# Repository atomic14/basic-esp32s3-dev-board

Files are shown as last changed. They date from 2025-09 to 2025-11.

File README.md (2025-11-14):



# Very Basic ESP32-S3 Dev Board

More details available with this video [here](https://youtu.be/YMnd2NHENCI)

Design Video (https://www.youtube.com/watch?v=enlcWor7sPM)

Assembly Video (https://youtu.be/KziOUBjNtWw)

This is a super simple ESP32-S3 Dev Board with the bare mininum required to get it working.



We have:

- USB-C connector with 5.1K pull down resistors on CC1 and CC2
- 3V3 LDO Regulator
- Decoupling Capacitors
- indicated LEDs - 5V, 3V3, GPIO21

Things that we don't have:

- Additonal ESD protection on the USB port
- Battery charging and power path control
- Any exciting peripherals

## Schematic

- View the schematic PDF: [docs/schematic.pdf](docs/schematic.pdf)

Schematic

## PCB

PCB Render

- 3D Model (STEP): [docs/dev-board.step](docs/dev-board.step)

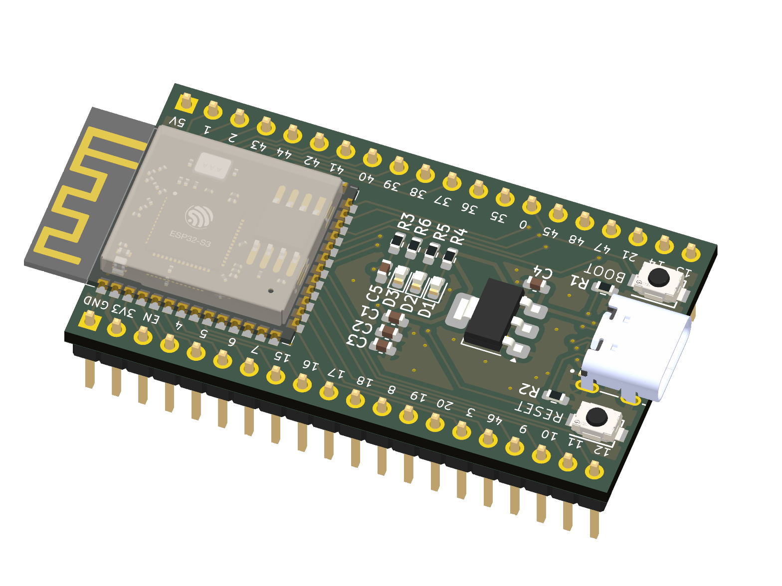
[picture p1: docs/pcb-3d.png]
3D Model


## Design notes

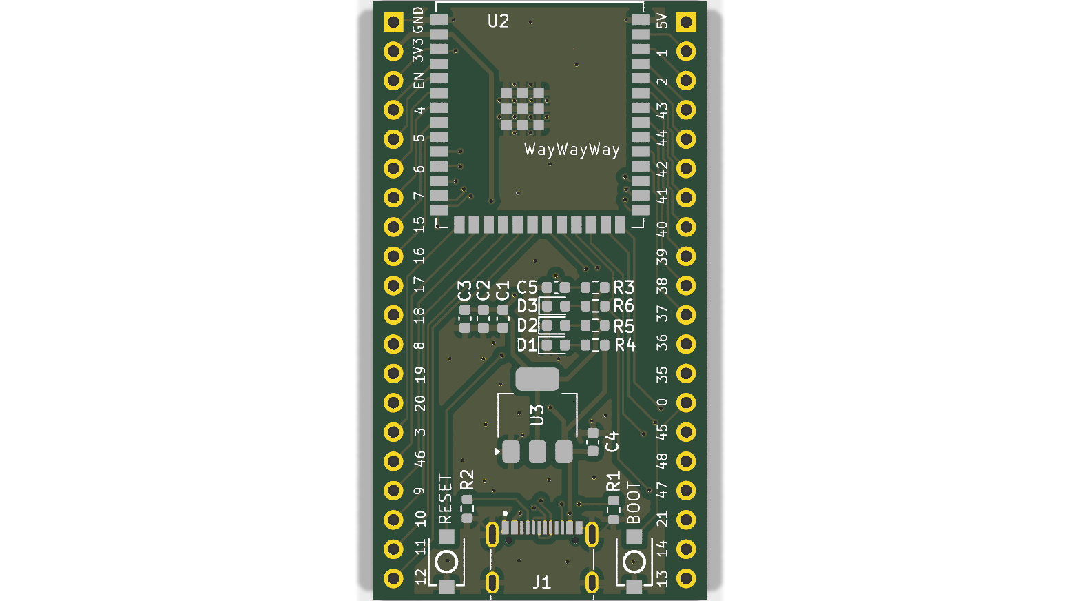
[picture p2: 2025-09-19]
docs/pcb.png

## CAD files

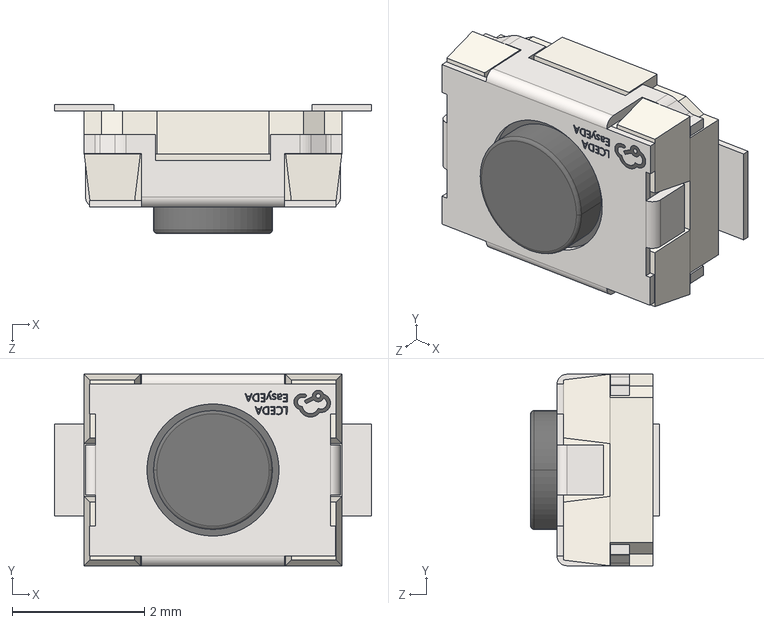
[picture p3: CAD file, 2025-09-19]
3d-models/SW-SMD_L3.9-W2.9-H2.0-LS4.8.step
4.80 x 2.90 x 1.95 mm

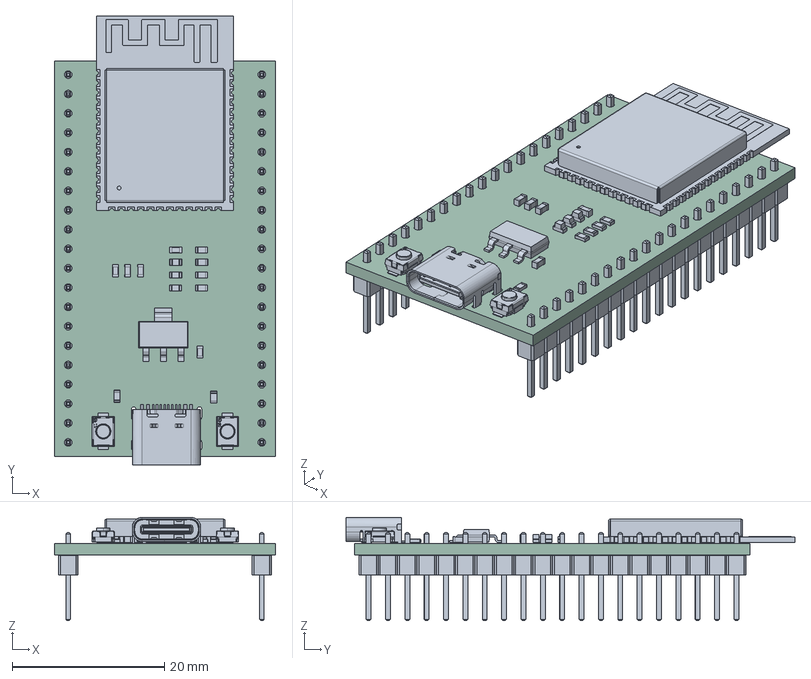
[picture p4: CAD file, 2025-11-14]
docs/dev-board.step
29.0 x 58.9 x 13.5 mm
R_0603_1608Metric x 6
SW-SMD_L3.9-W2.9-H2.0-LS4.8 x 2
LED_0603_1608Metric x 3
C_0603_1608Metric x 5
TYPE-C-31-M-12
SOT-223
C0201_20210301.STEP^C0201_20210301.STEP_Submodel-C0201_part_ DesignRootModel_PCB_ESP32-S3-WROOM-1_V1(2)_PCB_ESP32-S3-WROOM-1_V1 x 14
L0201_20210301.STEP^L0201_20210301.STEP_Submodel-L0201_part_ DesignRootModel_PCB_ESP32-S3-WROOM-1_V1(2)_PCB_ESP32-S3-WROOM-1_V1 x 3
C0402_20210301.STEP^C0402_20210301.STEP_Submodel-C0402_part_ DesignRootModel_PCB_ESP32-S3-WROOM-1_V1(2)_PCB_ESP32-S3-WROOM-1_V1
R0201_20210301.STEP^R0201_20210301.STEP_Submodel-R0201_part_ DesignRootModel_PCB_ESP32-S3-WROOM-1_V1(2)_PCB_ESP32-S3-WROOM-1_V1 x 8
trace_1^Submodel-MINI-ANT-TYPEB_668419613_part_DesignRootModel_PCB_ ESP32-S3-WROOM-1_V1(2)_PCB_ESP32-S3-WROOM-1_V1
DFN1006.STEP^DFN1006.STEP_Submodel-SOD882_part_DesignRootModel_PCB_ ESP32-S3-WROOM-1_V1(2)_PCB_ESP32-S3-WROOM-1_V1
SOP8_rev1_20210308.STEP^SOP8_rev1_20210308.STEP_Submodel-SOP8_1P27_6P6_ part_DesignRootModel_PCB_ESP32-S3-WROOM-1_V1(2)_PCB_ESP32-S3-WROOM-1_V1
XTAL3225_20210301.STEP^XTAL3225_20210301.STEP_Submodel-XTAL3225_part_ DesignRootModel_PCB_ESP32-S3-WROOM-1_V1(2)_PCB_ESP32-S3-WROOM-1_V1
ESP32-S3_20210301.STEP^ESP32-S3_20210301.STEP_Submodel-QFN56_0P4_7_ part_DesignRootModel_PCB_ESP32-S3-WROOM-1_V1(2)_PCB_ESP32-S3-WROOM-1_V1
uid__4-128^DesignRootModel_PCB_ESP32-S3-WROOM-1_V1(2)_PCB_ ESP32-S3-WROOM-1_V1
uid__4-129^DesignRootModel_PCB_ESP32-S3-WROOM-1_V1(2)_PCB_ ESP32-S3-WROOM-1_V1
uid__4-130^DesignRootModel_PCB_ESP32-S3-WROOM-1_V1(2)_PCB_ ESP32-S3-WROOM-1_V1
uid__4-149^DesignRootModel_PCB_ESP32-S3-WROOM-1_V1(2)_PCB_ ESP32-S3-WROOM-1_V1
uid__4-150^DesignRootModel_PCB_ESP32-S3-WROOM-1_V1(2)_PCB_ ESP32-S3-WROOM-1_V1
uid__4-151^DesignRootModel_PCB_ESP32-S3-WROOM-1_V1(2)_PCB_ ESP32-S3-WROOM-1_V1
uid__4-167^DesignRootModel_PCB_ESP32-S3-WROOM-1_V1(2)_PCB_ ESP32-S3-WROOM-1_V1
uid__4-168^DesignRootModel_PCB_ESP32-S3-WROOM-1_V1(2)_PCB_ ESP32-S3-WROOM-1_V1
uid__4-169^DesignRootModel_PCB_ESP32-S3-WROOM-1_V1(2)_PCB_ ESP32-S3-WROOM-1_V1
uid__1-279^DesignRootModel_PCB_ESP32-S3-WROOM-1_V1(2)_PCB_ ESP32-S3-WROOM-1_V1
uid__1-280^DesignRootModel_PCB_ESP32-S3-WROOM-1_V1(2)_PCB_ ESP32-S3-WROOM-1_V1
uid__1-292^DesignRootModel_PCB_ESP32-S3-WROOM-1_V1(2)_PCB_ ESP32-S3-WROOM-1_V1
uid__1-298^DesignRootModel_PCB_ESP32-S3-WROOM-1_V1(2)_PCB_ ESP32-S3-WROOM-1_V1
uid__1-299^DesignRootModel_PCB_ESP32-S3-WROOM-1_V1(2)_PCB_ ESP32-S3-WROOM-1_V1
uid__1-300^DesignRootModel_PCB_ESP32-S3-WROOM-1_V1(2)_PCB_ ESP32-S3-WROOM-1_V1
uid__1-301^DesignRootModel_PCB_ESP32-S3-WROOM-1_V1(2)_PCB_ ESP32-S3-WROOM-1_V1
uid__1-304^DesignRootModel_PCB_ESP32-S3-WROOM-1_V1(2)_PCB_ ESP32-S3-WROOM-1_V1
uid__1-305^DesignRootModel_PCB_ESP32-S3-WROOM-1_V1(2)_PCB_ ESP32-S3-WROOM-1_V1
uid__1-308^DesignRootModel_PCB_ESP32-S3-WROOM-1_V1(2)_PCB_ ESP32-S3-WROOM-1_V1
uid__1-310^DesignRootModel_PCB_ESP32-S3-WROOM-1_V1(2)_PCB_ ESP32-S3-WROOM-1_V1
uid__1-311^DesignRootModel_PCB_ESP32-S3-WROOM-1_V1(2)_PCB_ ESP32-S3-WROOM-1_V1
uid__1-325^DesignRootModel_PCB_ESP32-S3-WROOM-1_V1(2)_PCB_ ESP32-S3-WROOM-1_V1
uid__1-334^DesignRootModel_PCB_ESP32-S3-WROOM-1_V1(2)_PCB_ ESP32-S3-WROOM-1_V1
uid__1-338^DesignRootModel_PCB_ESP32-S3-WROOM-1_V1(2)_PCB_ ESP32-S3-WROOM-1_V1
uid__1-339^DesignRootModel_PCB_ESP32-S3-WROOM-1_V1(2)_PCB_ ESP32-S3-WROOM-1_V1
uid__1-340^DesignRootModel_PCB_ESP32-S3-WROOM-1_V1(2)_PCB_ ESP32-S3-WROOM-1_V1
uid__1-343^DesignRootModel_PCB_ESP32-S3-WROOM-1_V1(2)_PCB_ ESP32-S3-WROOM-1_V1
uid__1-344^DesignRootModel_PCB_ESP32-S3-WROOM-1_V1(2)_PCB_ ESP32-S3-WROOM-1_V1
uid__1-345^DesignRootModel_PCB_ESP32-S3-WROOM-1_V1(2)_PCB_ ESP32-S3-WROOM-1_V1
uid__1-352^DesignRootModel_PCB_ESP32-S3-WROOM-1_V1(2)_PCB_ ESP32-S3-WROOM-1_V1
uid__1-354^DesignRootModel_PCB_ESP32-S3-WROOM-1_V1(2)_PCB_ ESP32-S3-WROOM-1_V1
uid__1-355^DesignRootModel_PCB_ESP32-S3-WROOM-1_V1(2)_PCB_ ESP32-S3-WROOM-1_V1
uid__1-357^DesignRootModel_PCB_ESP32-S3-WROOM-1_V1(2)_PCB_ ESP32-S3-WROOM-1_V1
uid__1-358^DesignRootModel_PCB_ESP32-S3-WROOM-1_V1(2)_PCB_ ESP32-S3-WROOM-1_V1
uid__1-359^DesignRootModel_PCB_ESP32-S3-WROOM-1_V1(2)_PCB_ ESP32-S3-WROOM-1_V1
uid__1-364^DesignRootModel_PCB_ESP32-S3-WROOM-1_V1(2)_PCB_ ESP32-S3-WROOM-1_V1
uid__1-365^DesignRootModel_PCB_ESP32-S3-WROOM-1_V1(2)_PCB_ ESP32-S3-WROOM-1_V1
uid__1-371^DesignRootModel_PCB_ESP32-S3-WROOM-1_V1(2)_PCB_ ESP32-S3-WROOM-1_V1
uid__1-375^DesignRootModel_PCB_ESP32-S3-WROOM-1_V1(2)_PCB_ ESP32-S3-WROOM-1_V1
uid__1-376^DesignRootModel_PCB_ESP32-S3-WROOM-1_V1(2)_PCB_ ESP32-S3-WROOM-1_V1
uid__1-378^DesignRootModel_PCB_ESP32-S3-WROOM-1_V1(2)_PCB_ ESP32-S3-WROOM-1_V1
uid__1-379^DesignRootModel_PCB_ESP32-S3-WROOM-1_V1(2)_PCB_ ESP32-S3-WROOM-1_V1
uid__1-380^DesignRootModel_PCB_ESP32-S3-WROOM-1_V1(2)_PCB_ ESP32-S3-WROOM-1_V1
uid__1-381^DesignRootModel_PCB_ESP32-S3-WROOM-1_V1(2)_PCB_ ESP32-S3-WROOM-1_V1
uid__1-382^DesignRootModel_PCB_ESP32-S3-WROOM-1_V1(2)_PCB_ ESP32-S3-WROOM-1_V1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

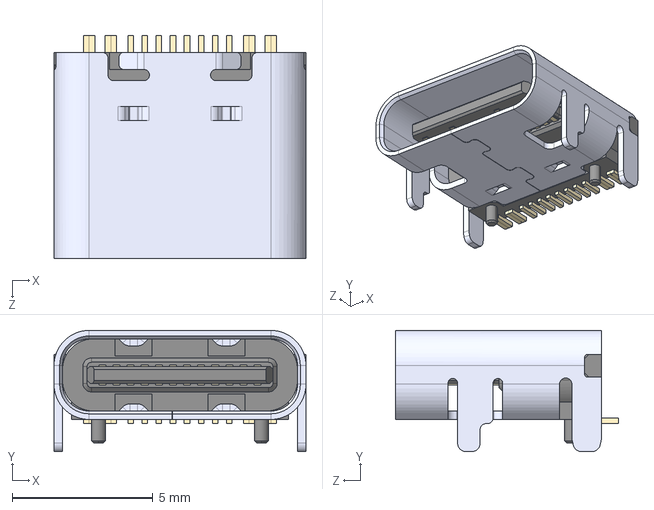
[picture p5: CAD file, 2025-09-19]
3d-models/TYPE-C-31-M-12.step
8.94 x 4.30 x 7.90 mm

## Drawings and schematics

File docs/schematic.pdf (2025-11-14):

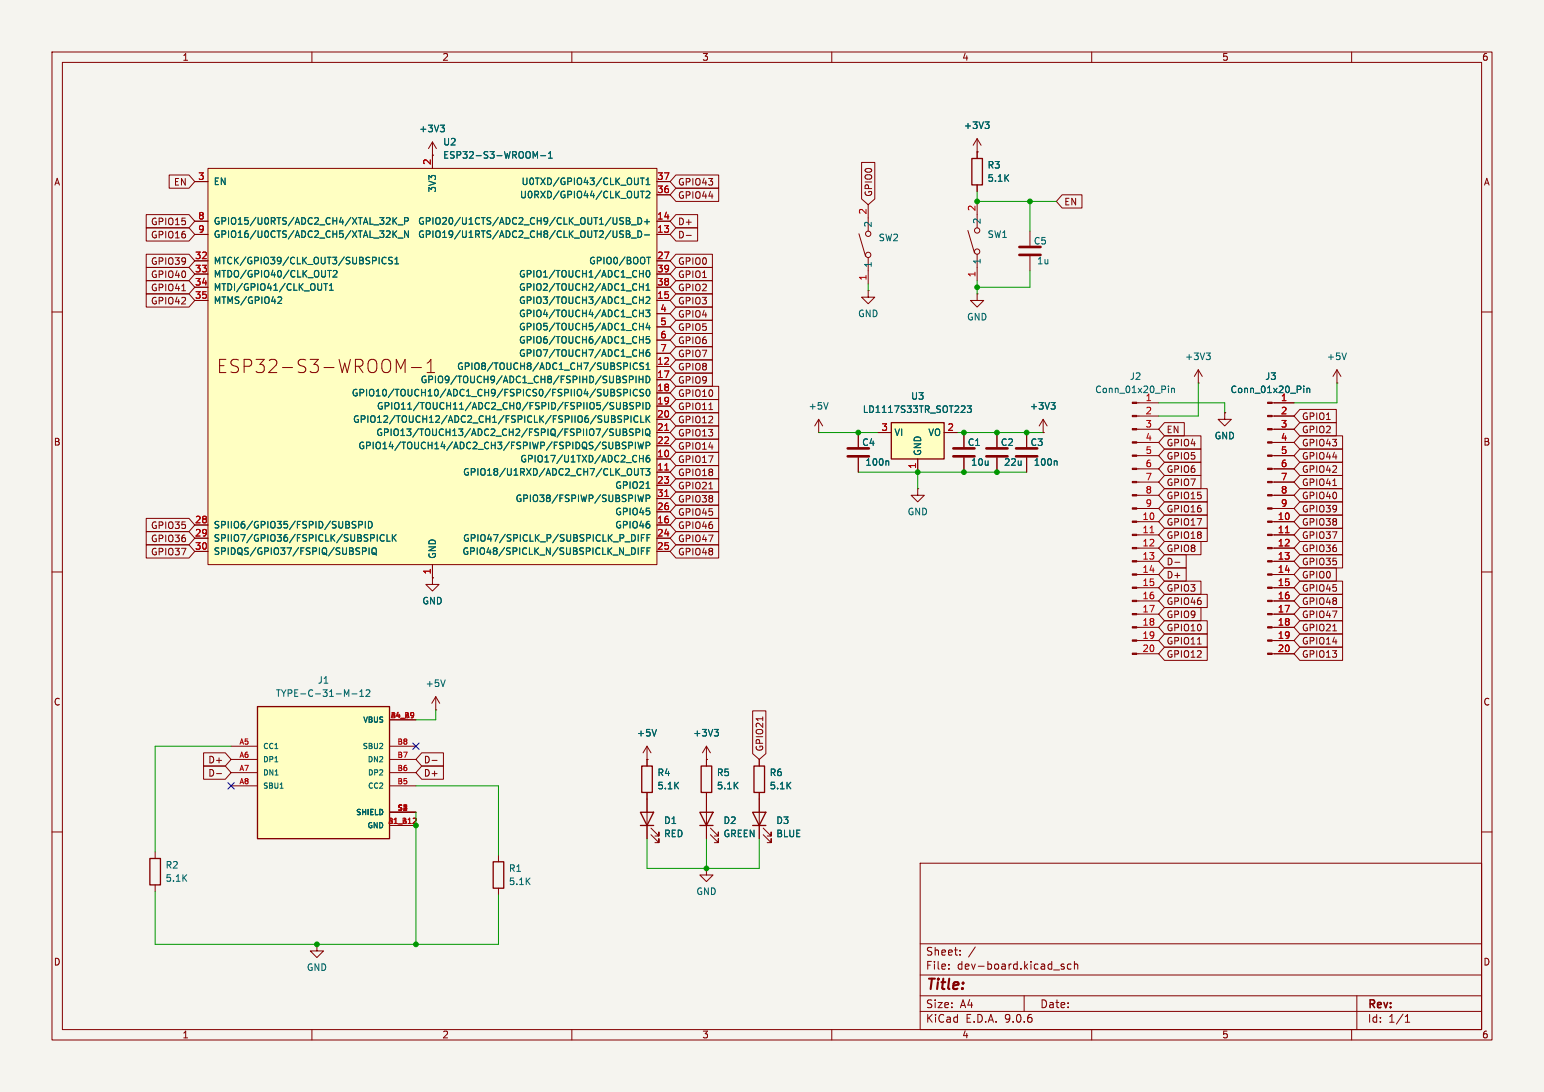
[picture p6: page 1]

1 U0TXD/GPIO43/CLK_OUT1 37 U0RXD/GPIO44/CLK_OUT2 36 GPIO20/U1CTS/ADC2_CH9/CLK_OUT1/USB_D+ 14 GPIO19/U1RTS/ADC2_CH8/CLK_OUT2/USB_D- 13 GPIO0/BOOT 27 GPIO1/TOUCH1/ADC1_CH0 39 GPIO2/TOUCH2/ADC1_CH1 38 GPIO3/TOUCH3/ADC1_CH2 15 GPIO4/TOUCH4/ADC1_CH3 4 GPIO5/TOUCH5/ADC1_CH4 5 GPIO6/TOUCH6/ADC1_CH5 6 GPIO7/TOUCH7/ADC1_CH6 7 GPIO8/TOUCH8/ADC1_CH7/SUBSPICS1 12 GPIO9/TOUCH9/ADC1_CH8/FSPIHD/SUBSPIHD 17 GPIO10/TOUCH10/ADC1_CH9/FSPICS0/FSPIIO4/SUBSPICS0 18 GPIO11/TOUCH11/ADC2_CH0/FSPID/FSPIIO5/SUBSPID 19 GPIO12/TOUCH12/ADC2_CH1/FSPICLK/FSPIIO6/SUBSPICLK 20 GPIO13/TOUCH13/ADC2_CH2/FSPIQ/FSPIIO7/SUBSPIQ 21 GPIO14/TOUCH14/ADC2_CH3/FSPIWP/FSPIDQS/SUBSPIWP 22 GPIO17/U1TXD/ADC2_CH6 10 GPIO18/U1RXD/ADC2_CH7/CLK_OUT3 11 GPIO21 23 GPIO38/FSPIWP/SUBSPIWP 31 GPIO45 26 GPIO46 16 GPIO47/SPICLK_P/SUBSPICLK_P_DIFF 24 GPIO48/SPICLK_N/SUBSPICLK_N_DIFF 25 U2ESP32-S3-WROOM-1 R6

1 U0TXD/GPIO43/CLK_OUT1 37 U0RXD/GPIO44/CLK_OUT2 36 GPIO20/U1CTS/ADC2_CH9/CLK_OUT1/USB_D+ 14 GPIO19/U1RTS/ADC2_CH8/CLK_OUT2/USB_D- 13 GPIO0/BOOT 27 GPIO1/TOUCH1/ADC1_CH0 39 GPIO2/TOUCH2/ADC1_CH1 38 GPIO3/TOUCH3/ADC1_CH2 15 GPIO4/TOUCH4/ADC1_CH3 4 GPIO5/TOUCH5/ADC1_CH4 5 GPIO6/TOUCH6/ADC1_CH5 6 GPIO7/TOUCH7/ADC1_CH6 7 GPIO8/TOUCH8/ADC1_CH7/SUBSPICS1 12 GPIO9/TOUCH9/ADC1_CH8/FSPIHD/SUBSPIHD 17 GPIO10/TOUCH10/ADC1_CH9/FSPICS0/FSPIIO4/SUBSPICS0 18 GPIO11/TOUCH11/ADC2_CH0/FSPID/FSPIIO5/SUBSPID 19 GPIO12/TOUCH12/ADC2_CH1/FSPICLK/FSPIIO6/SUBSPICLK 20 GPIO13/TOUCH13/ADC2_CH2/FSPIQ/FSPIIO7/SUBSPIQ 21 GPIO14/TOUCH14/ADC2_CH3/FSPIWP/FSPIDQS/SUBSPIWP 22 GPIO17/U1TXD/ADC2_CH6 10 GPIO18/U1RXD/ADC2_CH7/CLK_OUT3 11 GPIO21 23 GPIO38/FSPIWP/SUBSPIWP 31 GPIO45 26 GPIO46 16 GPIO47/SPICLK_P/SUBSPICLK_P_DIFF 24 GPIO48/SPICLK_N/SUBSPICLK_N_DIFF 25 C3

Id: 1/1 Title: File: dev-board.kicad_sch Sheet: /

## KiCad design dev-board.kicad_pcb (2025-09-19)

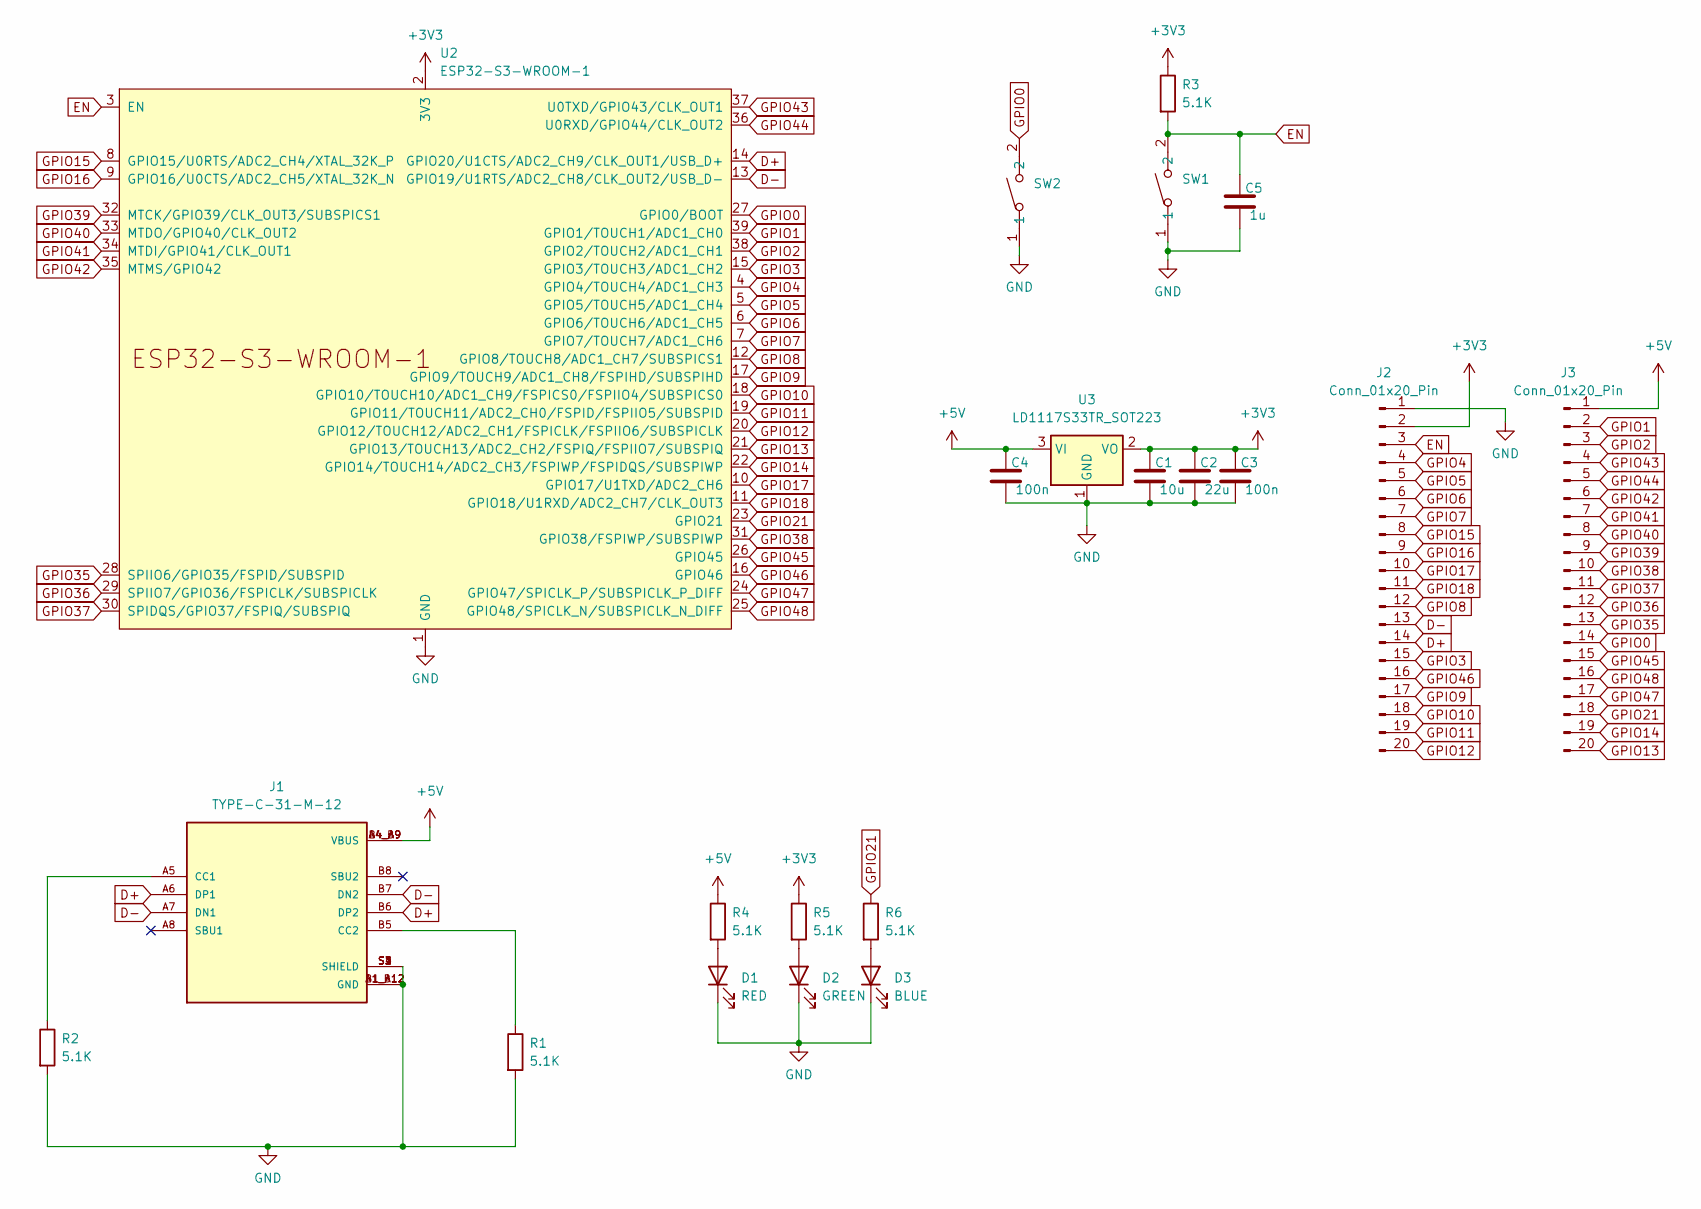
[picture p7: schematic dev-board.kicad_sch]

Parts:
C1: 10u; C_0603_1608Metric
C2: 22u; C_0603_1608Metric
C3, C4: 100n; C_0603_1608Metric
C5: 1u; C_0603_1608Metric
D1: RED; LED_0603_1608Metric
D2: GREEN; LED_0603_1608Metric
D3: BLUE; LED_0603_1608Metric
J1: TYPE-C-31-M-12; HRO_TYPE-C-31-M-12; PARTREV 2020.12.08
J2, J3: Conn_01x20_Pin; PinHeader_1x20_P2.54mm_Vertical
R1, R2, R3, R4, R5, R6: 5.1K; R_0603_1608Metric
SW1, SW2: TS-1088-AR02016; SW-SMD_L3.9-W3.0-P4.45; LCSC Part C720477
U2: ESP32-S3-WROOM-1
U3: LD1117S33TR_SOT223; SOT-223-3_TabPin2

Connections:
+3V3: C1.1, C2.1, C3.1, J2.2, R3.1, R5.1, U2.2 (3V3), U3.2 (VO)
+5V: C4.1, J1.A4_B9 (VBUS), J1.B4_A9 (VBUS), J3.1, R4.1, U3.3 (VI)
D+: J1.A6 (DP1), J1.B6 (DP2), J2.14, U2.14 (GPIO20/U1CTS/ADC2_CH9/CLK_OUT1/USB_D+)
D-: J1.A7 (DN1), J1.B7 (DN2), J2.13, U2.13 (GPIO19/U1RTS/ADC2_CH8/CLK_OUT2/USB_D-)
EN: C5.1, J2.3, R3.2, SW1.2, U2.3 (EN)
GND: C1.2, C2.2, C3.2, C4.2, C5.2, D1.1 (K), D2.1 (K), D3.1 (K), J1.A1_B12 (GND), J1.B1_A12 (GND), J1.S1 (SHIELD), J1.S2 (SHIELD), J1.S3 (SHIELD), J1.S4 (SHIELD), J2.1, R1.2, R2.2, SW1.1, SW2.1, U2.1 (GND), U2.40 (GND), U2.41 (GND), U3.1 (GND)
GPIO0: J3.14, SW2.2, U2.27 (GPIO0/BOOT)
GPIO1: J3.2, U2.39 (GPIO1/TOUCH1/ADC1_CH0)
GPIO2: J3.3, U2.38 (GPIO2/TOUCH2/ADC1_CH1)
GPIO3: J2.15, U2.15 (GPIO3/TOUCH3/ADC1_CH2)
GPIO4: J2.4, U2.4 (GPIO4/TOUCH4/ADC1_CH3)
GPIO5: J2.5, U2.5 (GPIO5/TOUCH5/ADC1_CH4)
GPIO6: J2.6, U2.6 (GPIO6/TOUCH6/ADC1_CH5)
GPIO7: J2.7, U2.7 (GPIO7/TOUCH7/ADC1_CH6)
GPIO8: J2.12, U2.12 (GPIO8/TOUCH8/ADC1_CH7/SUBSPICS1)
GPIO9: J2.17, U2.17 (GPIO9/TOUCH9/ADC1_CH8/FSPIHD/SUBSPIHD)
GPIO10: J2.18, U2.18 (GPIO10/TOUCH10/ADC1_CH9/FSPICS0/FSPIIO4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)
GPIO11: J2.19, U2.19 (GPIO11/TOUCH11/ADC2_CH0/FSPID/FSPIIO5/S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)
GPIO12: J2.20, U2.20 (GPIO12/TOUCH12/ADC2_CH1/FSPICLK/FSPIIO6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)
GPIO13: J3.20, U2.21 (GPIO13/TOUCH13/ADC2_CH2/FSPIQ/FSPIIO7/S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)
GPIO14: J3.19, U2.22 (GPIO14/TOUCH14/ADC2_CH3/FSPIWP/FSPIDQS/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)
GPIO15: J2.8, U2.8 (GPIO15/U0RTS/ADC2_CH4/XTAL_32K_P)
GPIO16: J2.9, U2.9 (GPIO16/U0CTS/ADC2_CH5/XTAL_32K_N)
GPIO17: J2.10, U2.10 (GPIO17/U1TXD/ADC2_CH6)
GPIO18: J2.11, U2.11 (GPIO18/U1RXD/ADC2_CH7/CLK_OUT3)
GPIO21: J3.18, R6.1, U2.23 (GPIO21)
GPIO35: J3.13, U2.28 (SPIIO6/GPIO35/FSPID/SUBSPID)
GPIO36: J3.12, U2.29 (SPIIO7/GPIO36/FSPICLK/SUBSPICLK)
GPIO37: J3.11, U2.30 (SPIDQS/GPIO37/FSPIQ/SUBSPIQ)
GPIO38: J3.10, U2.31 (GPIO38/FSPIWP/SUBSPIWP)
GPIO39: J3.9, U2.32 (MTCK/GPIO39/CLK_OUT3/SUBSPICS1)
GPIO40: J3.8, U2.33 (MTDO/GPIO40/CLK_OUT2)
GPIO41: J3.7, U2.34 (MTDI/GPIO41/CLK_OUT1)
GPIO42: J3.6, U2.35 (MTMS/GPIO42)
GPIO43: J3.4, U2.37 (U0TXD/GPIO43/CLK_OUT1)
GPIO44: J3.5, U2.36 (U0RXD/GPIO44/CLK_OUT2)
GPIO45: J3.15, U2.26 (GPIO45)
GPIO46: J2.16, U2.16 (GPIO46)
GPIO47: J3.17, U2.24 (GPIO47/SPICLK_P/SUBSPICLK_P_DIFF)
GPIO48: J3.16, U2.25 (GPIO48/SPICLK_N/SUBSPICLK_N_DIFF)
unnamed: D1.2 (A), R4.2
unnamed: D2.2 (A), R5.2
unnamed: D3.2 (A), R6.2
unnamed: J1.A5 (CC1), R2.1
unnamed: J1.B5 (CC2), R1.1

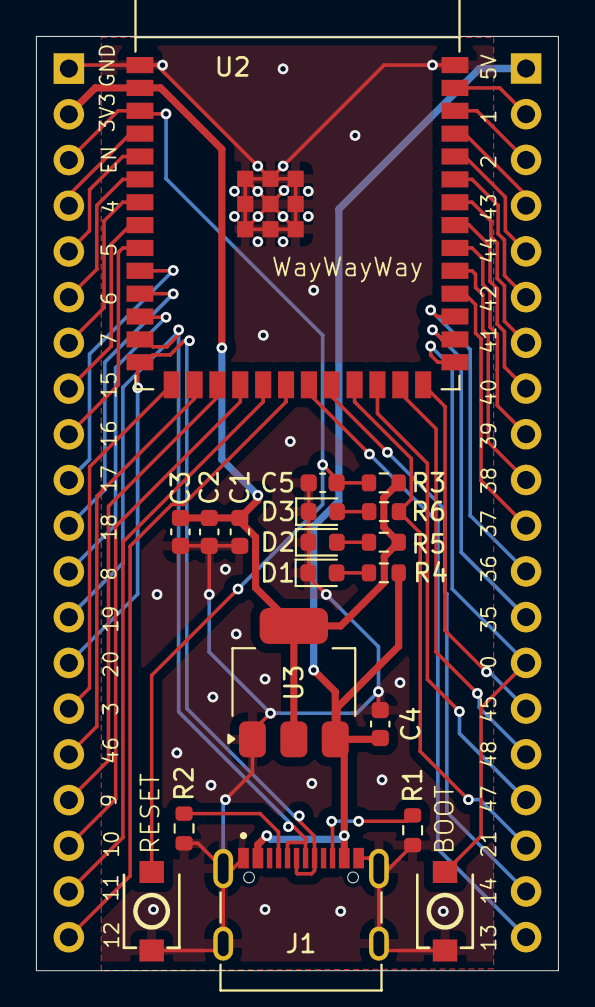
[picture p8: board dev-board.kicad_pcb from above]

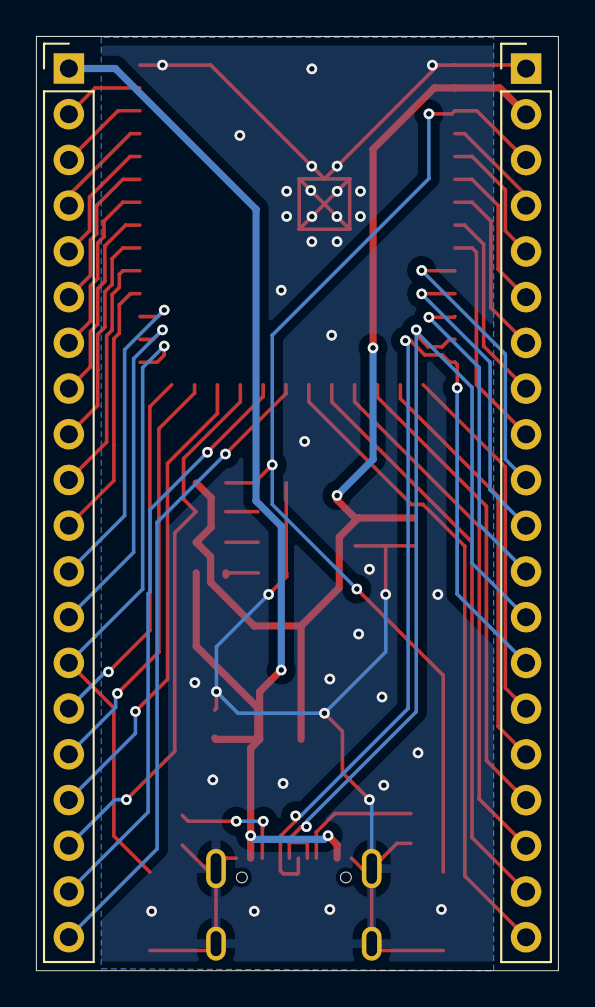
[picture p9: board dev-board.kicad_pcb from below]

Board: 2 copper layers, 29.0 x 51.9 mm, 21 parts (2 on the bottom side), 45 nets.

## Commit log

2025-09-19 Update docs artifacts (schematic, PCB images, STEP) [skip ci]
2025-09-19 Fix 3d model parths
    [SW-SMD_L3.9-W2.9-H2.0-LS4.8.step, TYPE-C-31-M-12.step, dev-board.kicad_pcb]
2025-09-19 Fix path to schematic svg
